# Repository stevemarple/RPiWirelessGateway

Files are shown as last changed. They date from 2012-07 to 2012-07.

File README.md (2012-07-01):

# RPiWirelessGateway

A wireless gateway for the Raspberry Pi.

## Preliminary

Preliminary, untested design.

## License

The hardware design released under the Creative Commons Attribution-ShareAlike 
3.0 Unported (CC BY-SA 3.0) license, see 
http://creativecommons.org/licenses/by-sa/3.0/

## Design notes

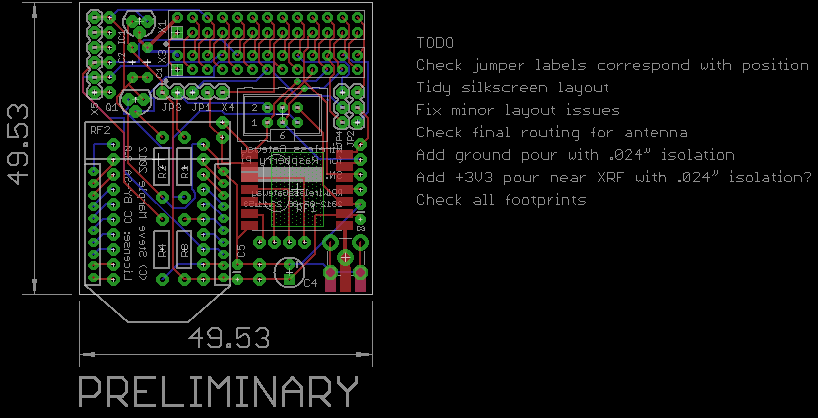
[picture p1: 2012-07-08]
hardware/RPiWirelessGateway_brd.png

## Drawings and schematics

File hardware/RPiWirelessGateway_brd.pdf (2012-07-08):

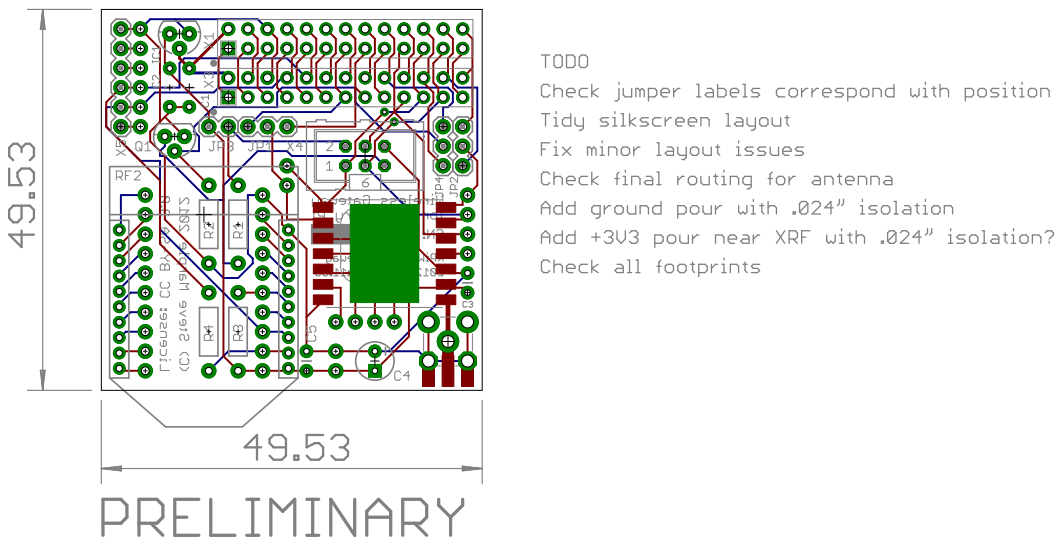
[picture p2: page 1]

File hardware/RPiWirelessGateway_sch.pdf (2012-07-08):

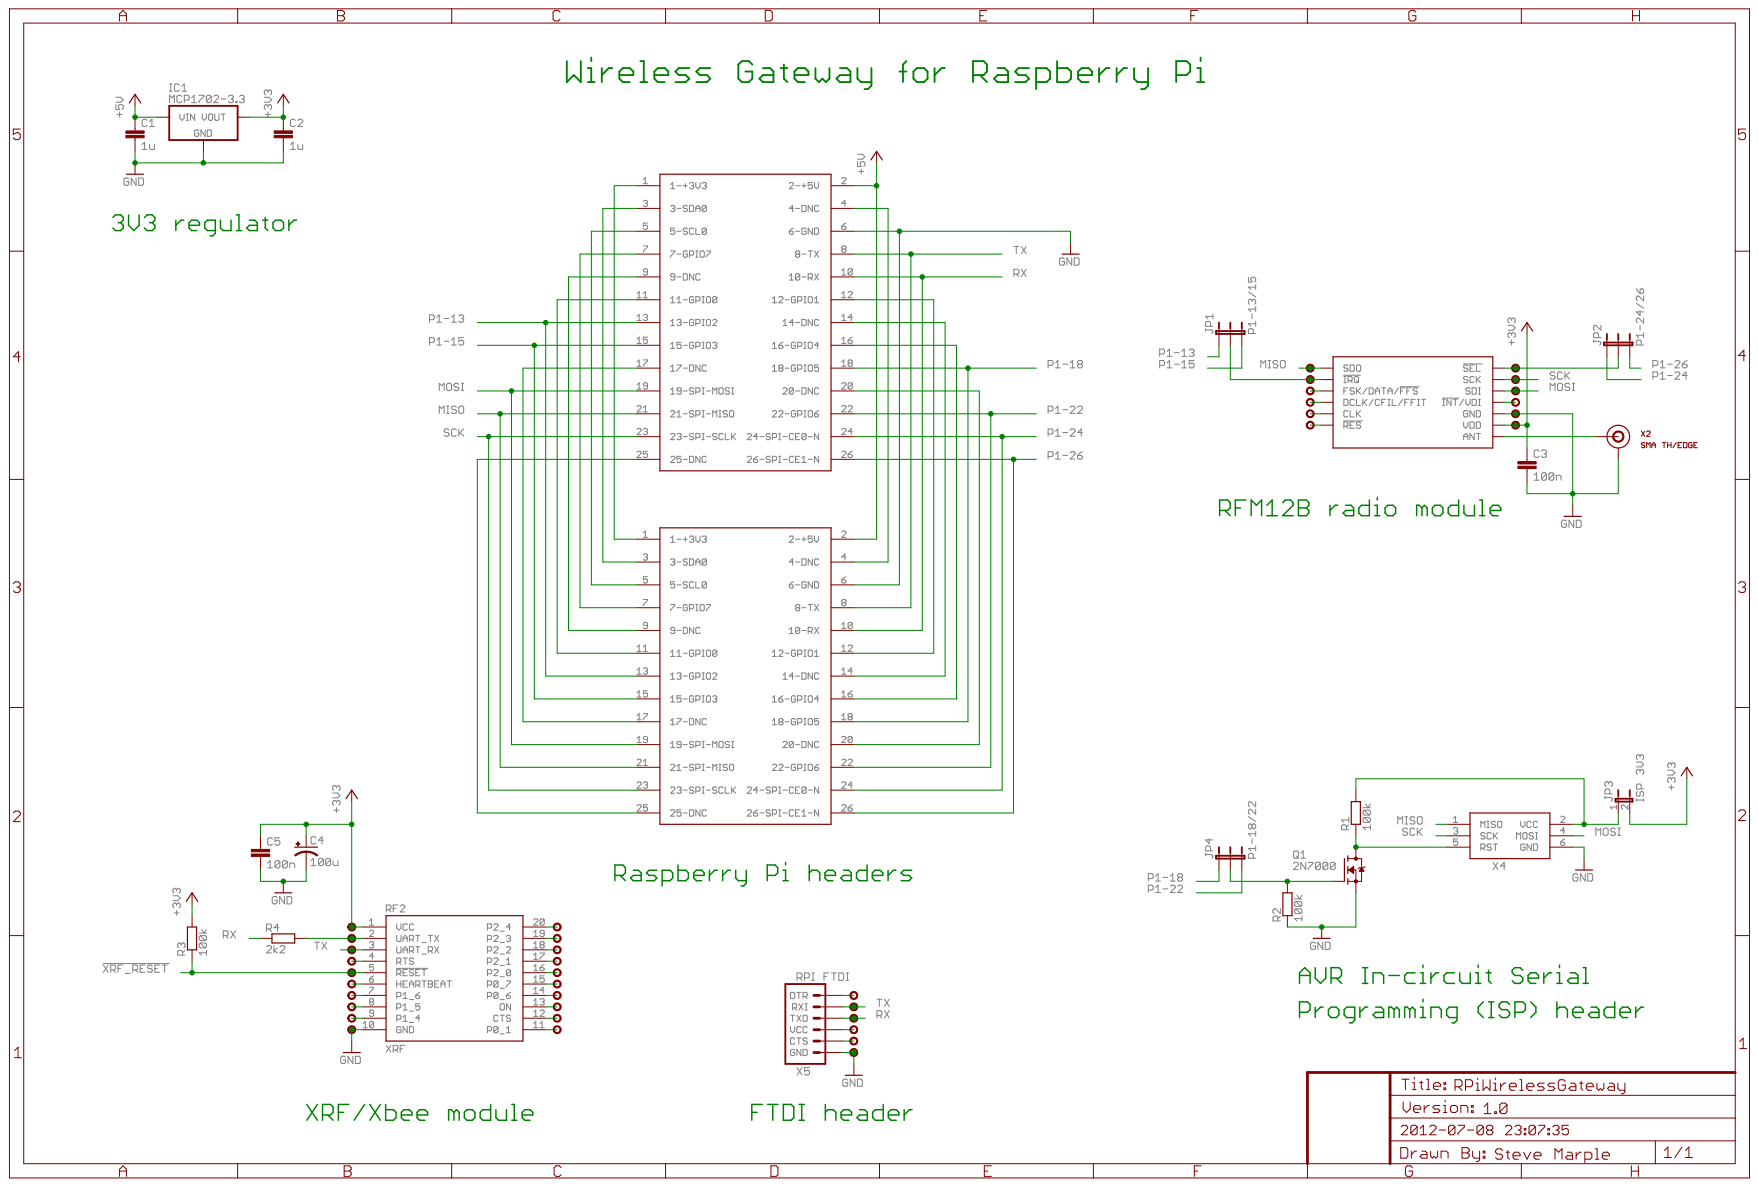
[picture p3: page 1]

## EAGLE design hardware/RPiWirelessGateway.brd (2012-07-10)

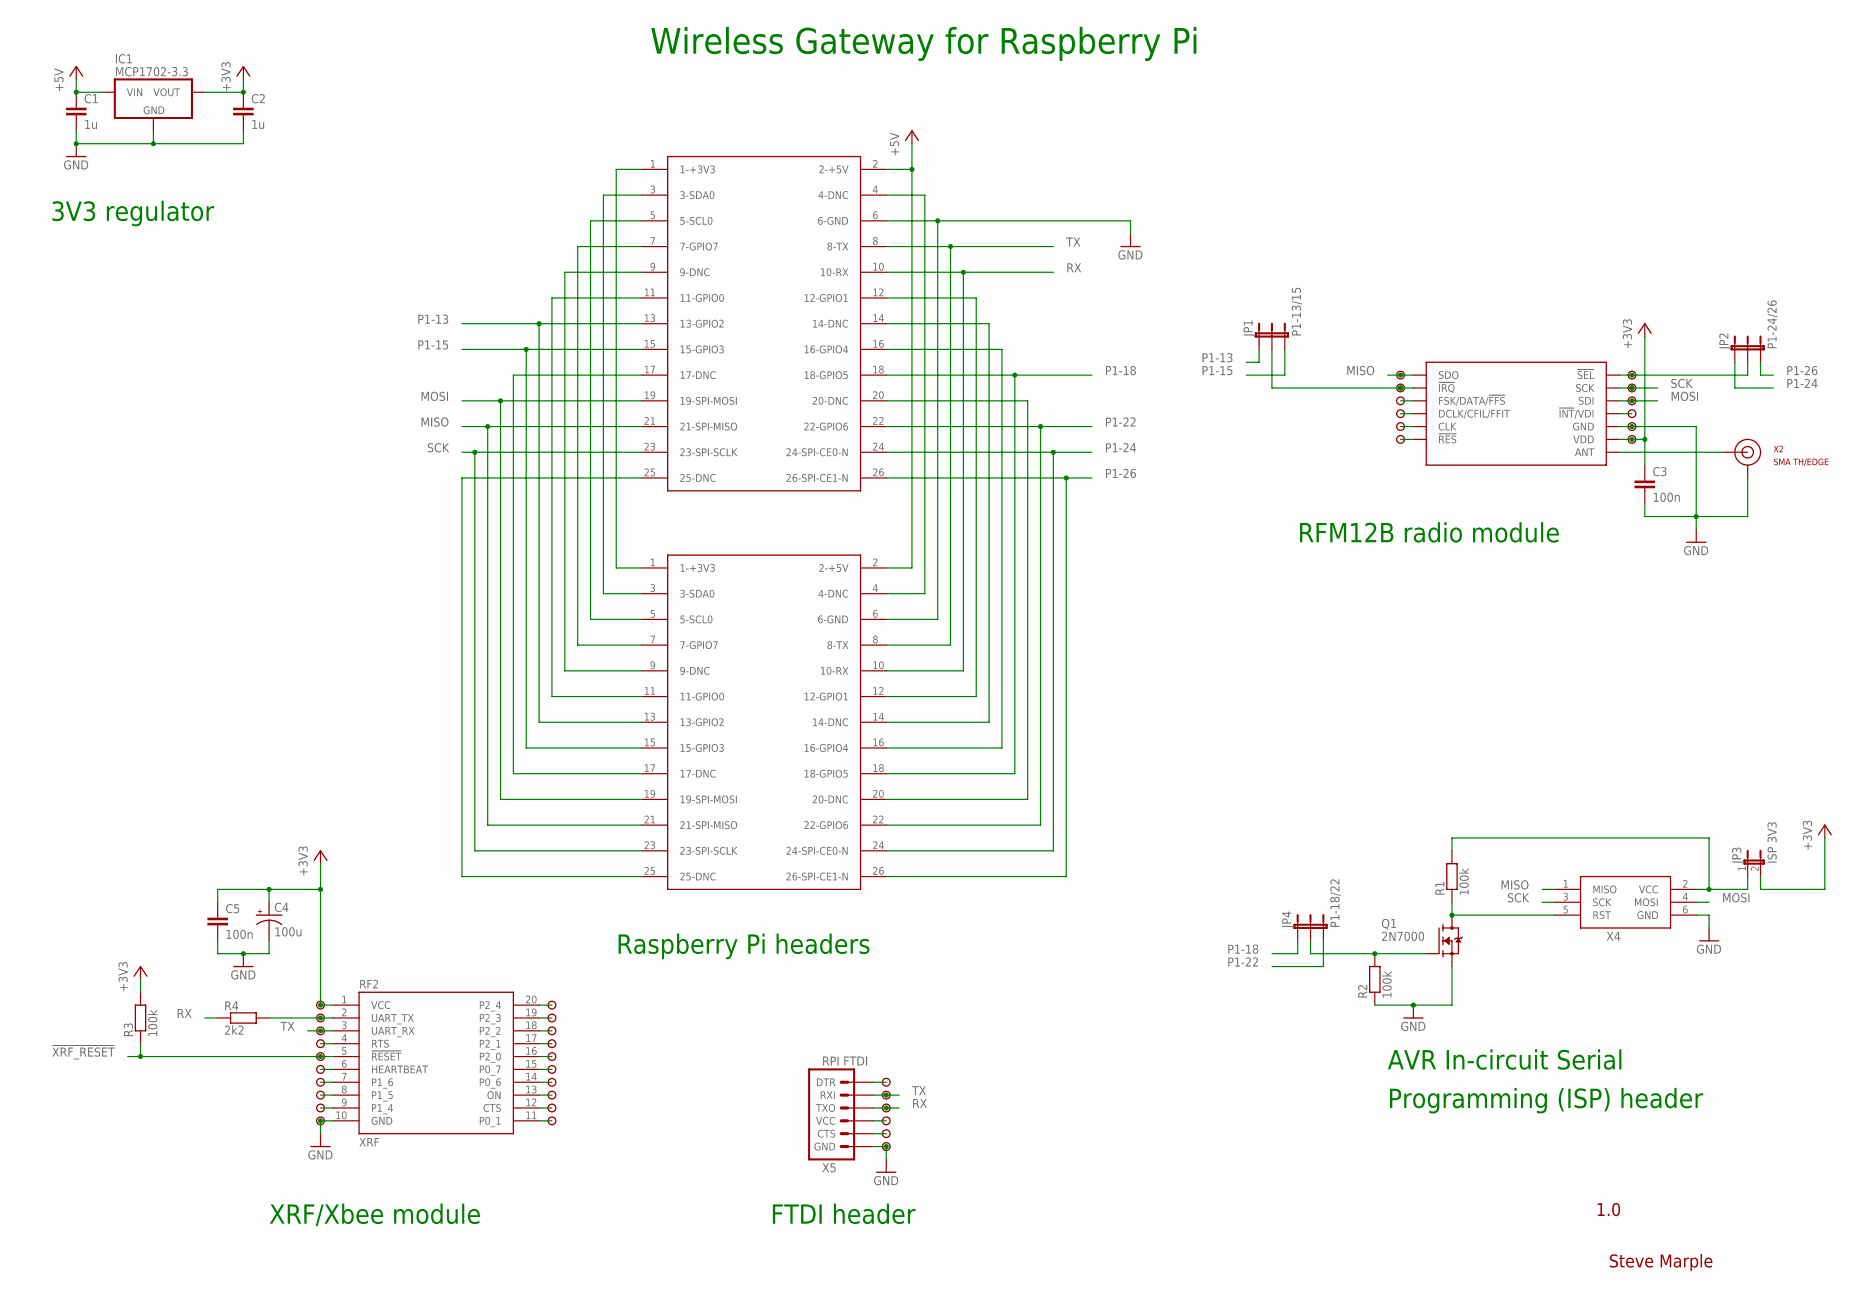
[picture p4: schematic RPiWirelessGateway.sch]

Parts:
C1, C2: 1u; CAP-PTH-5MM
C3, C5: 100n; CAP-PTH-SMALL
C4: 100u; CPOL-RADIAL-10UF-25V
IC1: MCP1702-3.3; TO-92
JP1: P1-13/15; 1X03
JP2: P1-24/26; 1X03
JP3: ISP 3V3; 1X02
JP4: P1-18/22; 1X03
PAD_RFM12B_!INT!/VDI, PAD_RFM12B_!INT!/VDI1, PAD_RFM12B_!INT!/VDI2, PAD_RFM12B_!IRQ, PAD_RFM12B_!RESET, PAD_RFM12B_!SEL, PAD_RFM12B_CLK, PAD_RFM12B_DCLK/CFIL/!FFS, PAD_RFM12B_FSK/DATA/!FFS, PAD_RFM12B_SCK, PAD_RFM12B_SDI, PAD_RFM12B_SDO: PAD
Q1: 2N7000; TO-92
R1, R2, R3: 100k; RES-AXIAL-0.4
R4: 2k2; RES-AXIAL-0.4
RF1: RFM12B
RF2: XRF; XBEE
U$1, U$2, U$3, U$4, U$5, U$6, U$7, U$8, U$9, U$10, U$11, U$12, U$13, U$14, U$15, U$16, U$17, U$18, U$19, U$20, U$21, U$22, U$23, U$24, U$25, U$26: PAD
X1: P1A; RASPBERRY-PI-HEADER
X2: SMA TH/EDGE; SMA-THD-EDGE
X3: P1B; RASPBERRY-PI-HEADER
X4: AVR ISP; CONN-HARTING-ML6
X5: RPI FTDI; 1X06-KIT

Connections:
!XRF_RESET: R3.P$1 (1), RF2.5 (!RESET), U$9.1
+3V3: C2.1, C3.1, C4.1 (+), C5.1, IC1.3 (VOUT), JP3.2, PAD_RFM12B_!INT!/VDI2.1, R3.P$2 (2), RF1.VDD, RF2.1 (VCC), U$1.1
+5V: C1.1, IC1.2 (VIN), X1.2 (2-+5V), X3.2 (2-+5V)
GND: C1.2, C2.2, C3.2, C4.2 (-), C5.2, IC1.1 (GND), PAD_RFM12B_!INT!/VDI1.1, Q1.1 (S), R2.P$1 (1), RF1.GND@0 (GND), RF1.GND@1 (GND), RF2.10 (GND), U$22.1, U$26.1, X1.6 (6-GND), X2.GND@0 (GND), X2.GND@1 (GND), X2.GND@2 (GND), X2.GND@3 (GND), X2.GND@EDGE0 (GND), X2.GND@EDGE1 (GND), X2.GND@EDGE2 (GND), X2.GND@EDGE3 (GND), X3.6 (6-GND), X4.6 (GND), X5.6 (GND)
MISO: PAD_RFM12B_SDO.1, RF1.SDO, X1.21 (21-SPI-MISO), X3.21 (21-SPI-MISO), X4.1 (MISO)
MOSI: PAD_RFM12B_SDI.1, RF1.SDI, X1.19 (19-SPI-MOSI), X3.19 (19-SPI-MOSI), X4.4 (MOSI)
unnamed: RF1.ANT, X2.SIG (SIGNAL), X2.SIG@EDGE (SIGNAL)
unnamed: JP2.2, PAD_RFM12B_!SEL.1, RF1.!SEL
unnamed: RF2.4 (RTS), U$7.1
unnamed: JP3.1, R1.P$2 (2), X4.2 (VCC)
unnamed: RF2.6 (HEARTBEAT), U$11.1
unnamed: RF2.7 (P1_6), U$13.1
unnamed: RF2.8 (P1_5), U$16.1
unnamed: RF2.9 (P1_4), U$19.1
unnamed: RF2.11 (P0_1), U$23.1
unnamed: RF2.12 (CTS), U$20.1
unnamed: RF2.13 (ON), U$17.1
unnamed: RF2.14 (P0_6), U$14.1
unnamed: RF2.15 (P0_7), U$12.1
unnamed: RF2.16 (P2_0), U$10.1
unnamed: RF2.17 (P2_1), U$8.1
unnamed: RF2.18 (P2_2), U$6.1
unnamed: RF2.19 (P2_3), U$4.1
unnamed: RF2.20 (P2_4), U$2.1
unnamed: PAD_RFM12B_!INT!/VDI.1, RF1.!INT!/VDI
unnamed: PAD_RFM12B_FSK/DATA/!FFS.1, RF1.FSK/DATA/!FFS
unnamed: PAD_RFM12B_DCLK/CFIL/!FFS.1, RF1.DCLK/CFIL/FFIT
unnamed: PAD_RFM12B_CLK.1, RF1.CLK
unnamed: PAD_RFM12B_!RESET.1, RF1.!RES
unnamed: Q1.3 (D), R1.P$1 (1), X4.5 (RST)
unnamed: X1.3 (3-SDA0), X3.3 (3-SDA0)
unnamed: X1.5 (5-SCL0), X3.5 (5-SCL0)
unnamed: X1.7 (7-GPIO7), X3.7 (7-GPIO7)
unnamed: X1.9 (9-DNC), X3.9 (9-DNC)
unnamed: X1.11 (11-GPIO0), X3.11 (11-GPIO0)
unnamed: U$25.1, X5.5 (CTS)
unnamed: U$24.1, X5.4 (VCC)
unnamed: X1.17 (17-DNC), X3.17 (17-DNC)
unnamed: X1.4 (4-DNC), X3.4 (4-DNC)
unnamed: X1.25 (25-DNC), X3.25 (25-DNC)
unnamed: X1.12 (12-GPIO1), X3.12 (12-GPIO1)
unnamed: X1.14 (14-DNC), X3.14 (14-DNC)
unnamed: X1.16 (16-GPIO4), X3.16 (16-GPIO4)
unnamed: JP4.2, Q1.2 (G), R2.P$2 (2)
unnamed: X1.20 (20-DNC), X3.20 (20-DNC)
unnamed: U$15.1, X5.1 (DTR)
unnamed: X1.1 (1-+3V3), X3.1 (1-+3V3)
unnamed: R4.P$2 (2), RF2.2 (UART_TX), U$3.1
P1-13: JP1.1, X1.13 (13-GPIO2), X3.13 (13-GPIO2)
P1-13/15: JP1.2, PAD_RFM12B_!IRQ.1, RF1.!IRQ
P1-15: JP1.3, X1.15 (15-GPIO3), X3.15 (15-GPIO3)
P1-18: JP4.1, X1.18 (18-GPIO5), X3.18 (18-GPIO5)
P1-22: JP4.3, X1.22 (22-GPIO6), X3.22 (22-GPIO6)
P1-24: JP2.1, X1.24 (24-SPI-CE0-N), X3.24 (24-SPI-CE0-N)
P1-26: JP2.3, X1.26 (26-SPI-CE1-N), X3.26 (26-SPI-CE1-N)
RX: R4.P$1 (1), U$21.1, X1.10 (10-RX), X3.10 (10-RX), X5.3 (TXO)
SCK: PAD_RFM12B_SCK.1, RF1.SCK, X1.23 (23-SPI-SCLK), X3.23 (23-SPI-SCLK), X4.3 (SCK)
TX: RF2.3 (UART_RX), U$5.1, U$18.1, X1.8 (8-TX), X3.8 (8-TX), X5.2 (RXI)

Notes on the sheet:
1.0
Steve Marple
Raspberry Pi headers
RFM12B radio module
XRF/Xbee module
AVR In-circuit Serial
Programming (ISP) header
FTDI header
3V3 regulator
Wireless Gateway for Raspberry Pi

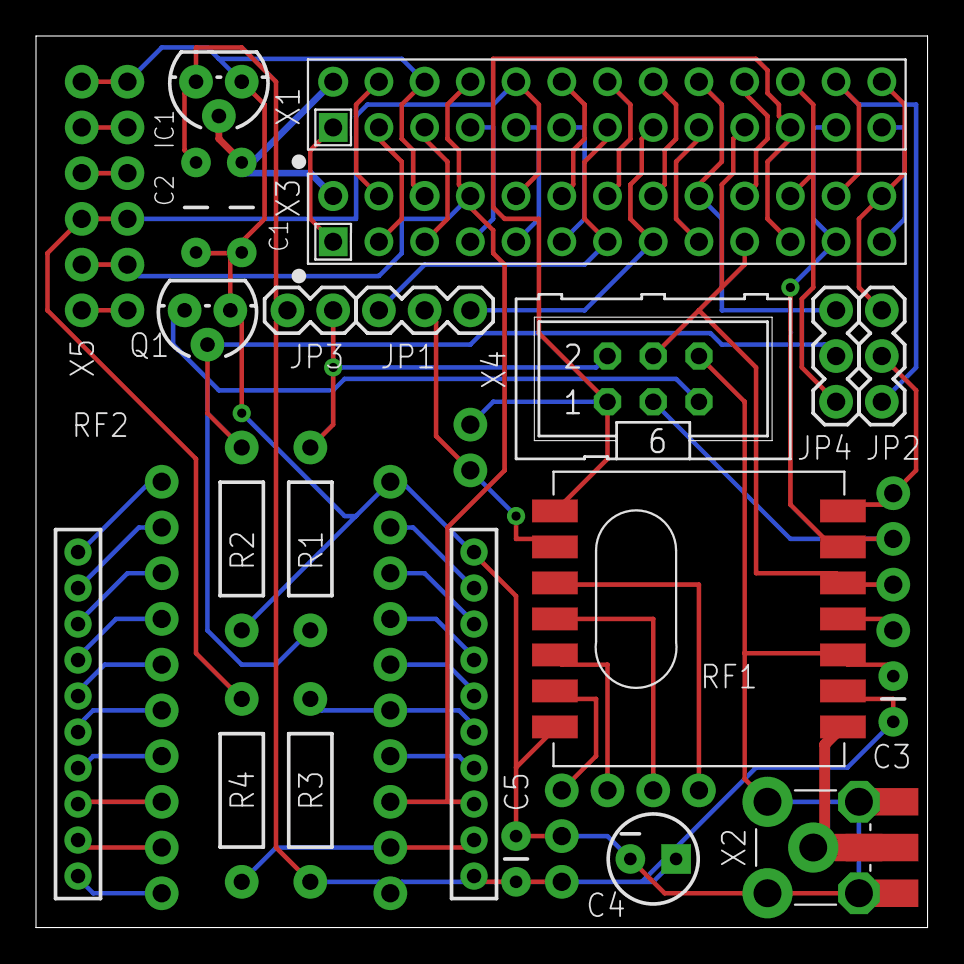
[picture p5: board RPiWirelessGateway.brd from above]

Board: 2 copper layers, 49.5 x 49.5 mm, 60 parts (0 on the bottom side), 58 nets.

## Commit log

2012-06-30 Adding preliminary hardware design files.
    [RPiWirelessGateway.brd, RPiWirelessGateway.sch]
2012-07-01 Adding resistor to XBee TX line to protect if FTDI also fitted simultaneously.
    [RPiWirelessGateway.brd, RPiWirelessGateway.sch]
2012-07-08 Adding FET for open-drain control of AVR /RESET
    [RPiWirelessGateway.brd, RPiWirelessGateway.sch]
2012-07-09 Added optional pull-up for /FFS. Move breakout pads for XRF/XBee to allow Sparkfun XBee breakout board to be fitted.
    [RPiWirelessGateway.brd, RPiWirelessGateway.sch]
2012-07-10 Removed pullup for /FFS (internal pullup present). New RFM12B footprint.
    [RPiWirelessGateway.brd, RPiWirelessGateway.sch]

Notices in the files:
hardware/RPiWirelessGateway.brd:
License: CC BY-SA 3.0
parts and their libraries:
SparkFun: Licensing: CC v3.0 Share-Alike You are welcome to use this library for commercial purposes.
